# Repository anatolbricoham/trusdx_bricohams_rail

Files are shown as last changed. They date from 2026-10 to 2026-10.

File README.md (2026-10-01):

# (tr)uSDX · Riel de batería modular — BricoHams

Integración compacta y modular para el transceptor QRP **(tr)uSDX**:

- **Carcasa** del equipo: *Housing for (tr)uSDX* de **DL2MAN** (sin cambios).
- **Batería** 3×18650: *battery-slider* de DL2MAN + *Battery Lead Cover* de **KD9WNR** (sin cambios).
- **Base**: *(tr)uSDX Stand with ATU-10 Enclosure* de **KD9WNR**, **modificada por BricoHams** con un **riel de cola de milano** en la trasera.

El riel usa **exactamente el mismo perfil de cola de milano que la tapa inferior con batería de DL2MAN**
(`bottom_cover_battery.stl`), con sus detents de clic. El mismo módulo de batería se monta:

| Dónde | Pieza que lo recibe |
|---|---|
| Directamente en la radio | `bottom_cover_battery.stl` (DL2MAN, original) |
| En la base / soporte | `trusdx-stand_battery-rail_BricoHams.stl` (este repo) |
| En un soporte ya impreso | `rail-adapter_glue-on_BricoHams.stl` (este repo, se pega) |

Cambias la batería de la radio a la base (o viceversa) en segundos, sin herramientas.

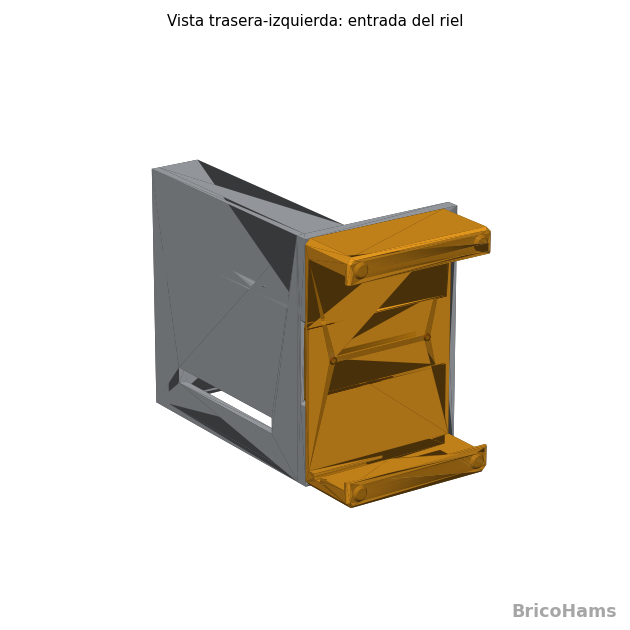
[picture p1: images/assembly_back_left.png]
Montaje


## Piezas a imprimir

| STL | Origen | Notas |
|---|---|---|
| `stl/trusdx-stand_battery-rail_BricoHams.stl` | **Nuevo** (remix KD9WNR) | Soporte con riel, tope y marca de agua |
| `stl/rail-adapter_glue-on_BricoHams.stl` | **Nuevo** | Opcional: riel suelto para pegar a un soporte ya impreso |
| `battery-slider.stl` *o* `battery-slider-witchusbcharger_dl1mad.stl` | DL2MAN / DL1MAD | Portapilas deslizante (descargar del original) |
| `trusdx-battery-lead-shroud.stl` | KD9WNR | Protector de los cables del portapilas |
| `stand-cover.stl`, `atu-10-enclosure.stl` | KD9WNR | Sin cambios |
| Carcasa completa | DL2MAN | Sin cambios |

`stl/_assembly_preview_DO-NOT-PRINT.stl` es solo para ver el conjunto montado.

## Documentación

1. [Proceso de diseño y medidas](docs/01_proceso_diseno.md)
2. [Impresión](docs/02_impresion.md)
3. [Montaje y cableado](docs/03_montaje.md)
4. [Atribución y licencias](ATTRIBUTION.md)

## Regenerar las piezas

```bash
pip install -r requirements.txt
python src/build.py --call EA4XXX     # tu indicativo en la marca de agua (opcional)
python src/render_previews.py         # imágenes de images/
```

Los parámetros (holguras, altura del tope, grosor…) están al principio de `src/build.py`.

## Licencia

Las piezas nuevas y modificadas: **CC BY-NC-SA 4.0** — ver [LICENSE.md](LICENSE.md).
Las piezas originales mantienen la licencia de sus autores — ver [ATTRIBUTION.md](ATTRIBUTION.md).

---
**BricoHams** · hecho por radioaficionados, para radioaficionados.

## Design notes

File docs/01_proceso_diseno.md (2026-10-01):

# 1 · Proceso de diseño

## Objetivo

Integrar la batería 3×18650 en la base del (tr)uSDX de forma **compacta**, **modular** (quitar y poner sin herramientas) y **compatible** con las piezas ya existentes en la comunidad.

## Análisis de las piezas originales

Todas las medidas se tomaron directamente de los STL publicados (secciones con `trimesh`).

### Carcasa DL2MAN

- Caja de 90 × 60 × 30 mm.
- `bottom_cover_battery.stl` es una tapa de 90 × 60 × 5 mm con una **ranura de cola de milano** a lo largo de los 60 mm.
- `battery-slider.stl` es un perfil en U de 90 × 29,5 × 60 mm para un portapilas 3×18650. Por detrás lleva la **lengüeta macho** que entra en esa ranura.

### Perfil de cola de milano (estándar DL2MAN)

| Elemento | Ranura (hembra, en la tapa) | Lengüeta (macho, en el slider) |
|---|---|---|
| Ancho en la boca | 27,2 mm | 25,2 mm (cuello) |
| Ancho en el fondo | 29,2 mm | 27,6 mm (punta) |
| Profundidad | 3,0 mm | 3,0 mm |
| Holgura lateral | — | aprox. 0,8–1,0 mm |
| Detents | 2 cavidades de 0,5 mm a 10 y 50 mm | 2 resaltes de 0,5 mm (Ø2 mm) a 10 y 50 mm |

Los resaltes de la lengüeta encajan en las cavidades de la ranura y producen el **clic** de retención.

### Soporte KD9WNR

- Cuña hueca de 92 × 59 × 90 mm (X: −40…52, Y: 9,8…68,8, Z: 0…90), abierta por abajo y cerrada con `stand-cover.stl`.
- La **cara trasera** es vertical y plana (y = 68,8) en toda su altura, con paredes de 3 mm.
- En la trasera hay una **ranura pasacables** en X −24…36 y Z 12,7…18,8.

## Decisiones de diseño

1. **Reutilizar el estándar DL2MAN** en vez de inventar un riel nuevo. Así el mismo slider sirve en la radio y en la base, y cualquier variante del slider (como la de DL1MAD con cargador USB-C) también encaja.
2. **Riel vertical en la trasera del soporte.** El slider entra desde arriba y apoya en un tope inferior, de modo que la gravedad también lo mantiene en su sitio. Es la cara más grande y plana, y no interfiere con la radio, la tapa inferior ni el ATU-10.
3. **Tope en Z = 28 mm.** La batería ocupa Z 28…88 y queda por encima de la ranura pasacables, que sigue libre para llevar los cables al compartimento interior.
4. **Placa-riel de 70 × 5 mm** (el mismo grosor que `bottom_cover_battery`). Se fusiona con la pared y añade solo 5 mm de fondo.
5. **Cuña de 45°** bajo la placa para imprimir sin soportes.
6. **Chaflán de entrada de 0,6 mm** en la boca de la ranura para que el slider entre suave.
7. **Marca de agua BricoHams:**
   - Grabada a 0,6 mm en la pared lateral izquierda, visible siempre.
   - En las bandas laterales del riel: BRICOHAMS y el indicativo (o "(tr)uSDX"), visibles al sacar la batería.

## Resultado

- El fondo total del conjunto es de unos 94 mm (soporte 59 + riel 5 + slider 29,5).
- Comprobación de interferencias con el slider original colocado, hecha con *booleanas* en `manifold3d`:
  - Asentado: 0,29 mm³, que es contacto coplanario sin interferencia real.
  - Desplazado 10 mm: unos 2,5 mm³. Es el resalte pasando por el fondo de la ranura, es decir, el clic.

## Parámetros (`src/build.py`)

| Parámetro | Valor | Uso |
|---|---|---|
| `DT_EXTRA` | 0,0 | Holgura extra por lado. Súbela a +0,1/+0,2 si el slider entra duro |
| `Z_STOP` | 28 | Altura del tope inferior |
| `PAD_W`, `PAD_T` | 70, 5 | Tamaño de la placa-riel |
| `DIMPLE_DEPTH` | 0,6 | Profundidad de los detents. Súbela para un clic más fuerte |
| `WM_TEXT` | BRICOHAMS | Texto de la marca de agua |
| `--call` | — | Indicativo en la banda derecha del riel y en el lateral |

## Herramientas

Python 3, `manifold3d` (booleanas robustas), `trimesh` (lectura y secciones de STL) y `matplotlib` (texto y vistas previas).

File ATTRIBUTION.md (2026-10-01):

# Atribución y licencias

Este proyecto es un *remix* que combina y modifica trabajos de la comunidad. Todos los créditos van a sus autores.

| Obra | Autor | Enlace | Licencia | Uso en este repo |
|---|---|---|---|---|
| Housing for (tr)uSDX QRP Transceiver | **DL2MAN** | https://www.printables.com/model/103619 | CC BY-SA 4.0 | Se usa el **perfil de cola de milano** medido de `bottom_cover_battery.stl` como referencia de compatibilidad. `vendor/battery-slider.stl` se incluye sin modificar para la vista de montaje |
| (tr)uSDX Battery Lead Cover | **Jim, KD9WNR** | https://www.printables.com/model/1097625 | CC BY-NC 4.0 | Se usa sin modificar (descárgalo del original) |
| (tr)uSDX Stand with ATU-10 Enclosure | **Jim, KD9WNR** (inspirado en W5AUG) | https://www.printables.com/model/737296 | CC BY-NC 4.0 | **Modificado**: riel de cola de milano, tope, cuña y marcas de agua. `vendor/trusdx-stand.stl` se incluye sin modificar como base del build |
| Battery slider with USB-C charger | **DL1MAD** (remix de DL2MAN) | https://www.printables.com/model/1339609 | CC BY-SA 4.0 | Compatible sin cambios |

PCB, esquemas y firmware del (tr)uSDX son de DL2MAN y PE1NNZ, bajo sus propias licencias (CC BY-ND según DL2MAN). Este proyecto **no** los toca.

## Licencia de las piezas nuevas o modificadas

`stl/*_BricoHams.stl`, `src/` e `images/`: **CC BY-NC-SA 4.0**, © BricoHams.

Se elige NC (no comercial) porque la base deriva de una obra CC BY-NC de KD9WNR, y SA para mantener el espíritu abierto del ecosistema DL2MAN.

Al redistribuir, cita a DL2MAN, KD9WNR y BricoHams, y enlaza a este repositorio.

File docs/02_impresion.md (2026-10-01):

# 2 · Impresión

## Ajustes recomendados (PETG)

| Ajuste | Soporte con riel | Adaptador | Slider DL2MAN |
|---|---|---|---|
| Altura de capa | 0,2 mm | 0,15 mm | 0,15 mm (recomendación de DL2MAN) |
| Paredes | 4 | 4 | 3 |
| Relleno | 20–25 % | 40 % | 20–25 % |
| Soportes | **No** | **No** | Según el original |
| Orientación | Tal cual viene en el STL (base abierta sobre la cama, riel vertical) | Cara de pegado sobre la cama | Según el original |
| Brim | 3–5 mm si la cama no agarra bien | No | No |

Temperaturas orientativas de PETG: boquilla a 235–245 °C, cama a 75–80 °C y ventilador al 30–50 %.

## Notas

- **Prueba de ajuste:** antes de imprimir el soporte entero (unas 6 h), imprime el **adaptador**, que es pequeño y rápido. Comprueba con él cómo desliza el slider:
  - Si entra duro, sube `DT_EXTRA` a 0,1–0,2 y regenera.
  - Si queda flojo y el clic no se nota, sube `DIMPLE_DEPTH` a 0,8.
- La marca de agua está grabada a 0,6 mm. Con boquilla de 0,4 se lee bien. Si quieres resaltarla, rellena el grabado con pintura acrílica y retira el sobrante.
- Si el laminador avisa de errores de malla en el soporte, vienen del STL original de KD9WNR. PrusaSlicer y Orca los reparan solos (opción "Reparar").
- Para la Anycubic Kobra S1 con PETG: limpia la cama con jabón, usa un brim de 3 mm y una primera capa lenta (20–30 mm/s).

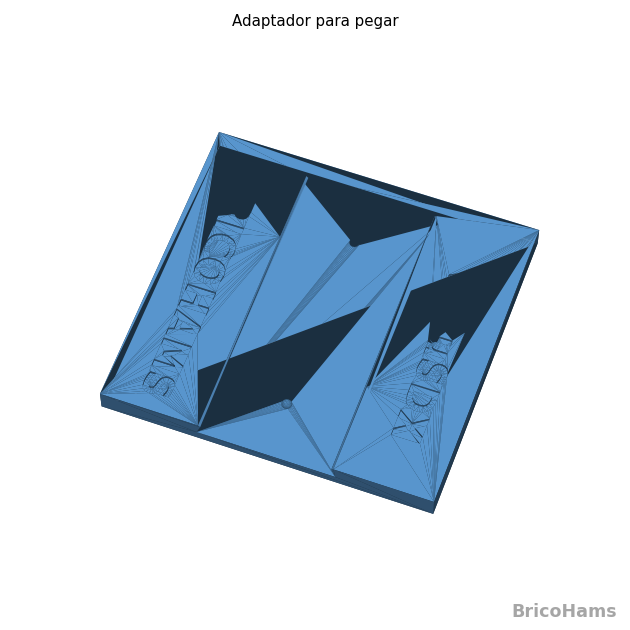
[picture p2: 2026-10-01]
images/adapter.png

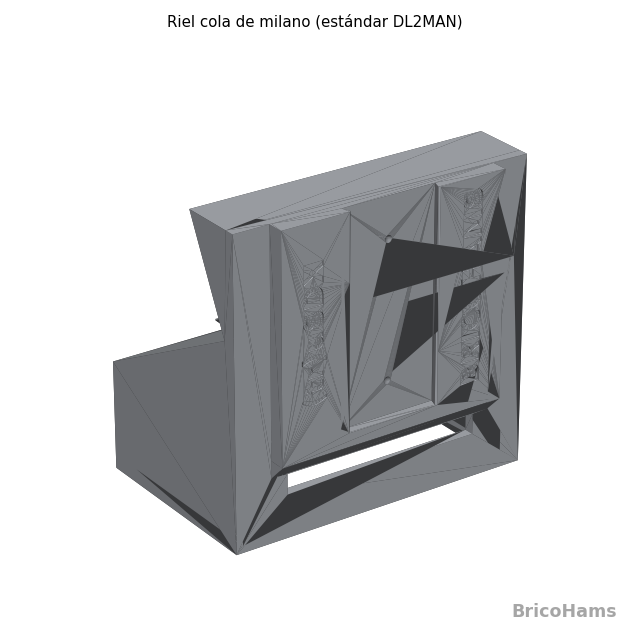
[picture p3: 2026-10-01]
images/stand_rail_back.png

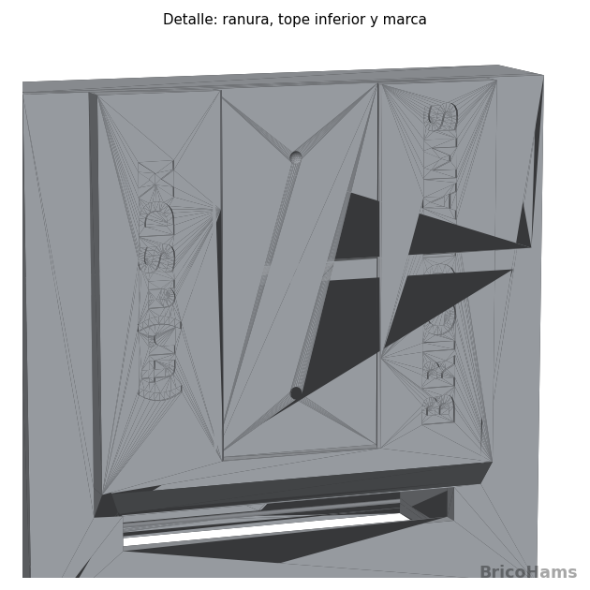
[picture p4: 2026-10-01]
images/rail_detail.png

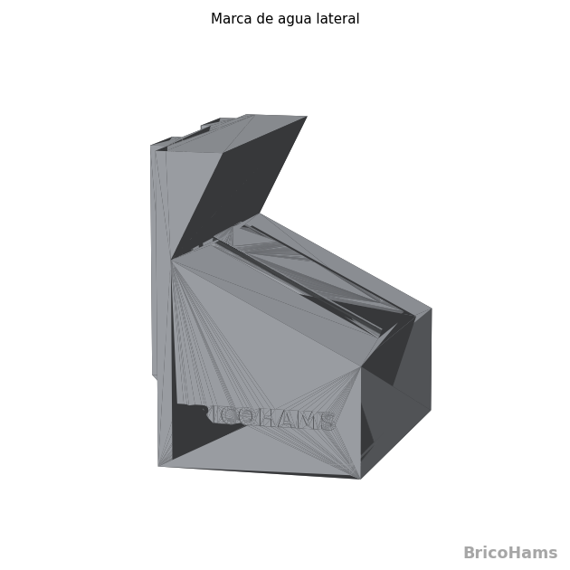
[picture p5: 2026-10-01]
images/stand_side_watermark.png

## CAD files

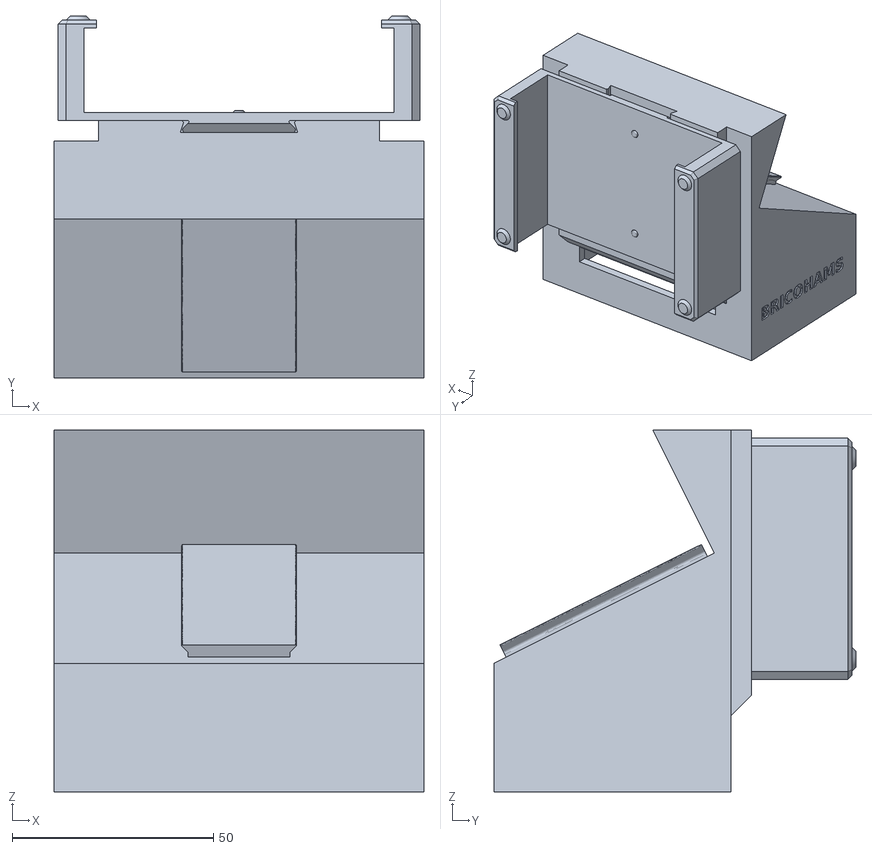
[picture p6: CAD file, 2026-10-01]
stl/_assembly_preview_DO-NOT-PRINT.stl
92.0 x 90.0 x 90.0

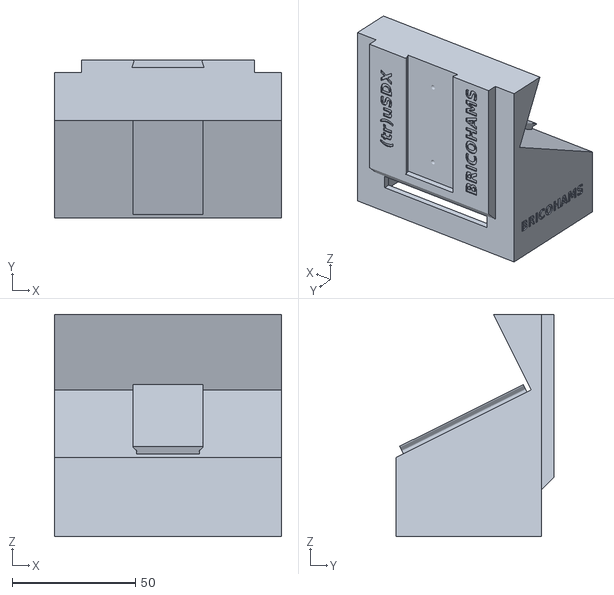
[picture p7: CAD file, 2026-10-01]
stl/trusdx-stand_battery-rail_BricoHams.stl
92.0 x 64.0 x 90.0

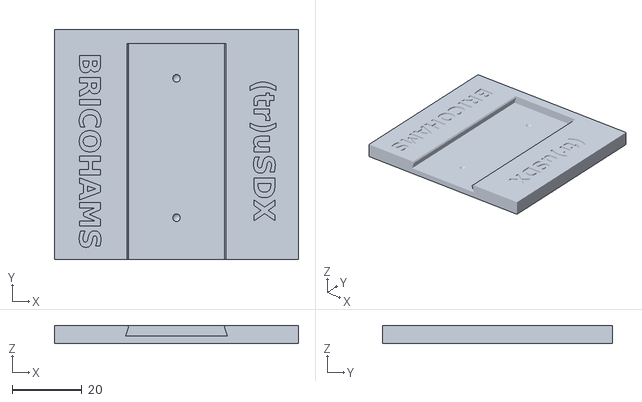
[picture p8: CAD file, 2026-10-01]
stl/rail-adapter_glue-on_BricoHams.stl
70.0 x 66.0 x 5.20

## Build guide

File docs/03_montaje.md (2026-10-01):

# 3 · Montaje y cableado

## Material

- Portapilas 3×18650, el mismo modelo para el que DL2MAN diseñó el slider (ver su ficha en Printables).
- 3 celdas 18650 **protegidas**, o una BMS 3S.
- *Battery Lead Cover* de KD9WNR y cianoacrilato.
- Cable de 22 AWG y el conector de alimentación del (tr)uSDX.
- Opcional: placa de carga USB-C para 3S, en la variante de DL1MAD.

> ⚠️ Un pack 3S de iones de litio llega a **12,6 V** con carga completa. Comprueba que esa tensión está dentro de lo que admite tu (tr)uSDX. Pon un fusible en serie y respeta la polaridad.

## Pasos

1. **Portapilas:**
   - Encaja el portapilas en el slider DL2MAN.
   - Desliza el protector de cables de KD9WNR por detrás del portapilas y fíjalo con una gota de CA.
   - Haz los empalmes dentro del protector.
2. **Orientación:** coloca el slider con los cables **hacia abajo**, para que salgan por la ranura pasacables del soporte.
3. **Montaje:** mete la lengüeta del slider en la ranura por la parte **superior** del soporte y deslízalo hacia abajo hasta el tope. Notarás el clic de los detents.
4. **Cableado:** pasa los cables por la ranura pasacables (Z 12–19 mm) hacia el compartimento interior. Allí puedes guardar el sobrante, el conector y el cable USB, y cerrarlo con `stand-cover.stl`.
5. **Radio:** coloca el (tr)uSDX en la pendiente del soporte como en el diseño original.
6. **Uso en portable:** saca el slider tirando hacia arriba y móntalo en la radio con `bottom_cover_battery.stl` de DL2MAN. El perfil es el mismo.

## Con ATU-10

El soporte sigue montando encima de `atu-10-enclosure.stl` igual que el original. El riel está en la trasera y no interfiere.

## Adaptador para pegar (soportes ya impresos)

1. Lija ligeramente la cara trasera del soporte y la cara plana del adaptador.
2. Coloca el adaptador centrado en X. Su borde inferior debe quedar a unos 24 mm del suelo, encima de la ranura pasacables.
3. Pégalo con epoxi de 5 min o con CA y activador, y deja curar antes de cargar la batería.

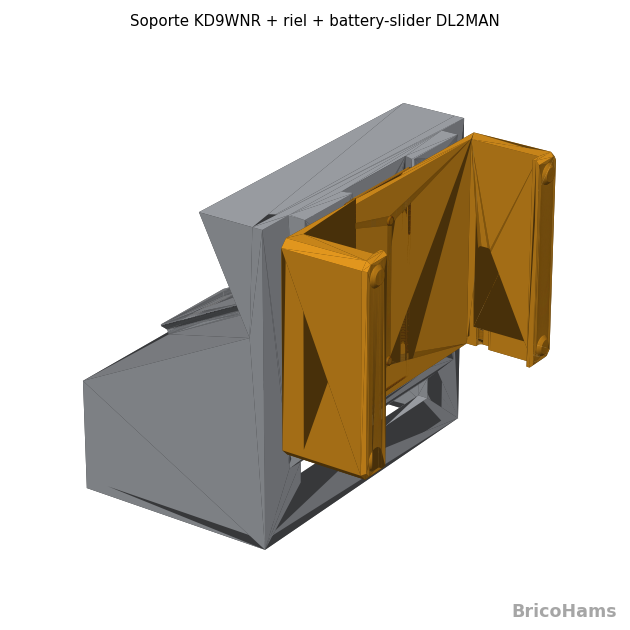
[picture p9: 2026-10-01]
images/assembly_back.png

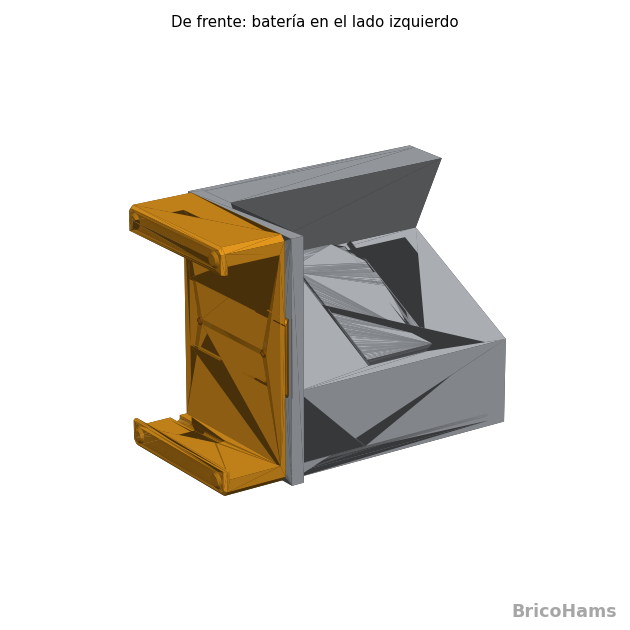
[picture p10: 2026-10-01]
images/assembly_front_left.png

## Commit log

2026-10-01 (tr)uSDX: riel de batería modular para el soporte KD9WNR (estándar cola de milano DL2MAN)
    - Soporte KD9WNR con riel vertical, tope, detents de clic y cuña sin soportes
    - Adaptador para pegar en soportes ya impresos
    - Marca de agua BricoHams
    - Script paramétrico (manifold3d), documentación y atribuciones
    Claude-Session: https://claude.ai/code/session_015JF9HLvVmTYGDRwB8vaZ2N
    [_assembly_preview_DO-NOT-PRINT.stl, rail-adapter_glue-on_BricoHams.stl, trusdx-stand_battery-rail_BricoHams.stl]
2026-10-01 Change assembly image from back to left view
    Updated assembly image reference in README.
2026-10-01 Change assembly image to back left view
    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
